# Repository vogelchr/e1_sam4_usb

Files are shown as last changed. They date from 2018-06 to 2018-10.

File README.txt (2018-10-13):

** Review comments for version

commit af33165416c78bff5535539db3183336a3adedb6
    Changed LIU to IDT82V2081.

OPEN:

* Board Bringup
	- due to PLL restrictions we cannot generate PCK 2.048 MHz, have
	  to live with SSC clk output (-> remove sam4s Pin 6,
	     PB3 to TX_CLK, PA21 to CLK2048)
	  
	- LIU spi interface configuration, pull SCLKE up (now: gnd)
	    SCLKE=low: shift SDO on rising edge of SCLK  (datasheet page 13)
	    SCLKE=high: shift SDO on falling edge of SCLK
	  SDI is *always* sampled on the rising edge, so to be consistent
	  SDI will be shifted on the falling edge, so should SDO and SCLKE
	  should be HIGH

	- rename LEDs to match net numbers (LED1..LED3)

* New Features

	For generating the E1 frame sync signal to the SSC peripheral:
	- bridge PA20/Pin16/RF (Receive Frame) to
	         PA27/Pin37/TIOB2 (Timer 2, IO B)
	         
	- bridge PA29/Pin41/TCLK2 (ext. clock input 2 to timer) to
	         PA19/Pin13/RK (Receive Clock)

* Repository / File Formats
	- rename .brd/.sch to sensible name, integrate in old
	   http://cgit.osmocom.org/osmo-e1-xcvr/ repository.

DONE after 20180624:
	- EAGLE 7 compatibility
		(exported _v7 files)
	- make JTAGSEL pullup DNP (JTAGSEL, TEST, ERASE should float)
	- ERASE jumper
	- pullups on i2c
	- pullups on SPI \CSn

	- possibly switch to 82V2081 LUI, as a few people have successfully
	  experimented with it, has access to nice stats over SPI
	  https://www.idt.com/products/interface-connectivity/telecom-interface-products/t1j1e1-interface-products/82v2081-1-channel-t1-j1-e1-short-haullong-haul-liu

DONE after 20180625:
	 - USB has no transient voltage suppressor, possible ESD damage
	 (recommended: IP4234CZ6)
	- R1 120 Ohms (LIU Rx term)
	- R2, R8 9 Ohms (LIU Tx in series)
	- LIU move signal from LOS to #INT 
	  -> Interrupt can be generated on LOS anyway.
	 - diescrete resistors instead of U$2 resistor array is probably lower
	cost in SMT, as it's a standard 10k resistor reel and not one more
	"cut-tape" reel only for that part
		-> introduced quad resistor packs 10k for various pullups
	 - for the DAC, it might make sense to align with what sylvain is using
	in his FPGA based design (and what sysmocom has used in other designs):
	MAX5215 (14bit). Could be upgraded to 16bit MAX5217 if ever needed.
	 - UART has not transient voltage suppressor, possible ESD damage
	(recommended: IP4234CZ6)
	 - JTAG connector doesn't appear to have standard 2x10 ARM-JTAG pin-out.
	If there's space I'd prefer a 20pin ARM-JTAG.
	 - SV3 serial pin-out could be aligned with FTDI 1x5 (or 1x6?) usb
	serial cables. I think it makes sense to align with pin-out of industry
	standard cables that people might already have
	- LEDs near frontpanel
	 - does SPI+I2C header (SV6) have UEXT compatible pin-out? If we use a
	 2x5 header, it might make senese to use the olimex-standard UEXT format
	 as there are plenty of other boards/devices with that pin-out
	 - !RESET has no pull-up, design is possibly susceptible to picking up
	RF/noise as reset trigger
	 - UART has no pull-up resistor on RxD input, i.e. floating input unless
	UART is connected
	- add pullup on LIU #RST
	 - GPS antenna input has no transient voltage suppressor, possible ESD
	damage (unless the
	GNS module has one inside? Did you find any documentation on that in
	the module data sheet? Recommended: 0603ESDA-TR

	 - GPS receiver rx/tx/pps doen't have series termination (27R or
	the like), possibly resulting in switching tranients degrading GPS
	performance

	(this was refused earlier, but later on implemented:)
	 - might make sense to add a precision voltage reference for the DAC,
	e.g. MAX6163ESA?

	- 33R series resistance in oscillator outputs

	- edge type SMA replaced by through hole (edge type incompatible
	  with frontpanel directly on board edge, would have meant to do
	  milling)

REFUSED:
	- interface to old LIU only board (SPI + DATA on pinheader)

	 - 1k series resistors for LEDs seems quite high resistance for 3.3V. I
	would usually expect 330..680 Ohms there?
	  => with modern LEDs it's really bright enough, even with 1k (or even 5k)

	 - If inverted-logic signals would use !SIGNAL instead of #SIGNAL, EAGLE
	would over-stroke their names
	  => (vogelchr) Nice, didn't know this, but will probably not change.

	- USB_VBUS_SENS not routed to microcontroller!
	  device is bus powered, hence monitoring not needed!

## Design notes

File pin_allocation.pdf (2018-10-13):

Po rtA

## Port A Functions

Port# | Pin | A | B | C | D | Extra | SystemNet
0 | 48 | PWMH0 | TIOA0 | A17 | WKUP0 | GPS_PPS
1 | 47 | PWMH1 | TIOB0 | A18 | WKUP1 | TP8
2 | 44 | PWMH2 | SCK0 | DATRG | WKUP2 | TP9
3 | 43 | TWD0 | NPCS3 | I2C
4 | 36 | TWCK0 | TCLK0 | WKUP3 | I2C
5 | 35 | RXD0 | NPCS3 | WKUP4 | GPS_RX
6 | 34 | TXD0 | PCK0 | GPS_TX
7 | 32 | RTS0 | PWMH3 | XIN32 LOS_LIU
8 | 31 | CTS0 | ADTRG | WKUP5 | XOUT32#RST_LIU
9 | 30 | URXD0 | NPCS1 | PWMFI0 | WKUP6 | URXD0_SAMBA_RX
10 | 29 | UTXD0 | NPCS2 | PWMFI1 | UTXD0_SAMBA_TX
11 | 28 | NPCS0 | PWMH0 | WKUP7 | #SPI_CS0
12 | 27 | MISO | PWMH1 | SPI_MISO
13 | 22 | MOSI | PWMH2 | SPI_MOSO
14 | 21 | SPCK | PWMH3 | WKUP8 | SPI_SCK
15 | 20 | TF | TIOA1 | PWML3 | WKUP14 /PIODCEN1 | TP13
16 | 19 | TK | TIOB1 | PWML2 | WKUP15/PIODCEN2 TX_CLK | input!
17 | 9 | TD | PCK1 | PWMH3 | AD0 | TX_DATA | output
18 | 10 | RD | PCK2 | A14 | PWMFI2AD1 | RX_DATA | inout
19 | 13 | RK | PWML0 | A15 | AD2 | RX_CLK | input
20 | 16 | RF | PWML1 | A16 | AD3 | (rx_frame) | TP10
21 | 11 | RXD1 | PCK1 | AD8 | CLK2048 (to LIU)
22 | 14 | TXD1 | NPCS3 | NCS2 | AD9 | TP11
23 | 15 | SCK1 | PWMH0 | A19 | PIODCCLK | TP12
24 | 23 | RTS1 | PWMH1 | A20 | PIODC0 | LED1
25 | 25 | CTS1 | PWMH2 | A23 | PIODC1 | LED2
26 | 26 | DCD1 | TIOA2 | MCDA2 | PIODC2 | LED3
27 | 37 | DTR1 | TIOB2 | MCDA3 | PIODC3 | (rx_frame) | TP14
28 | 38 | DSR1 | TCLK1 | MCCDA | PIODC4 | TP15
29 | 41 | RI1 | TCLK2 | MCCK | PIODC5 | TP16
30 | 42 | PWML2 | NPCS2 | MCDA0 | WKUP11/PIODC6 | SPI_CS2
31 | 52 | NPCS1 | PCK2 | MCDA1 | PIODC7 | SPI_CS1
Inst | TC0 PWM TWI0 UART0 USART0 USART1 SSC SPI

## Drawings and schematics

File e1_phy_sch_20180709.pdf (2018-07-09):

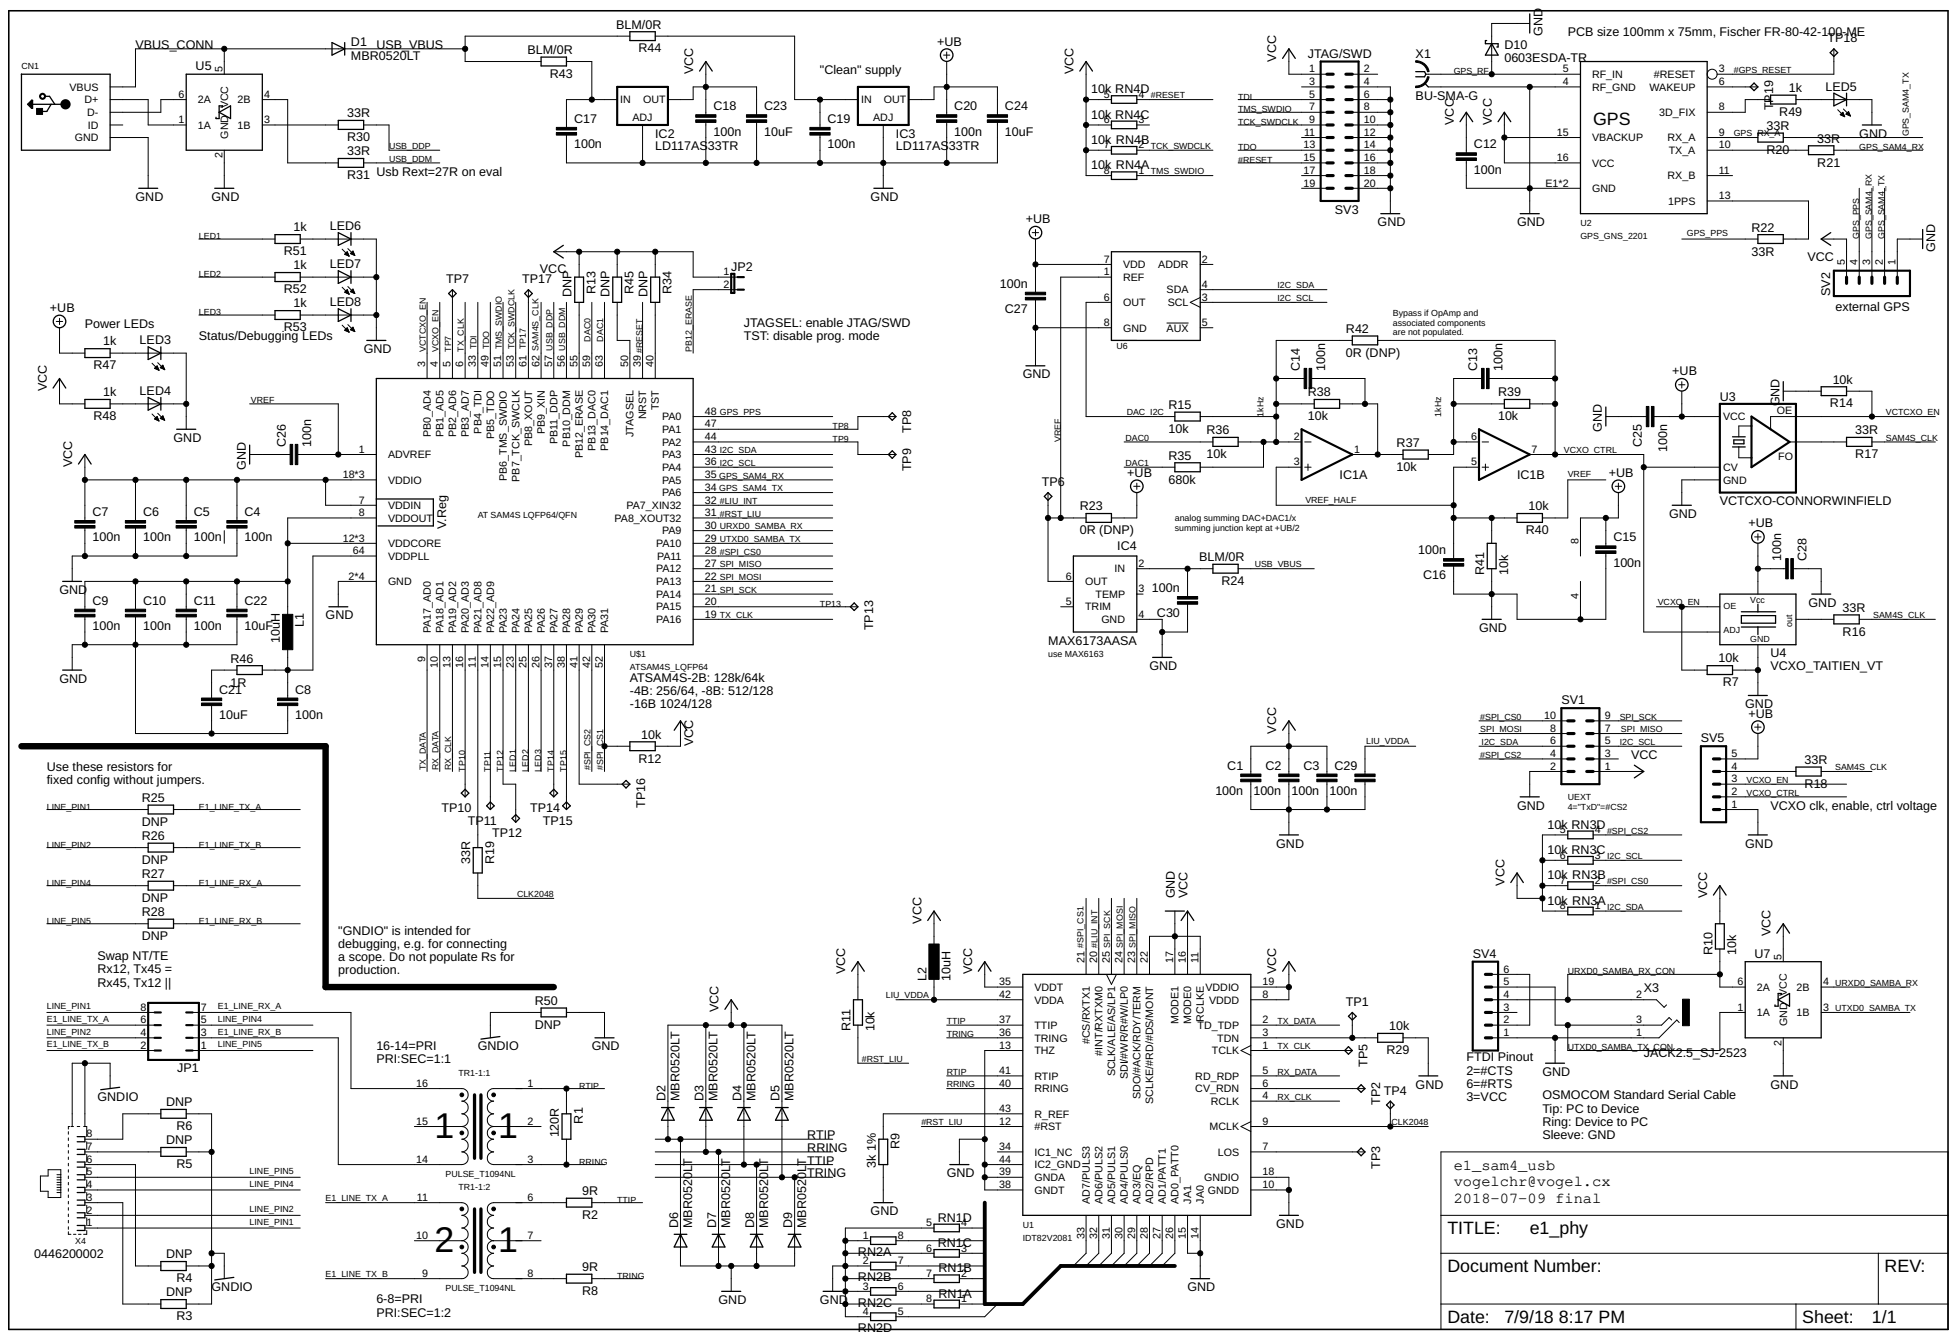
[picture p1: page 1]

PCB size 100mm x 75mm, Fischer FR-80-42-100-ME

Bypass if OpAmp and
associated components are not populated.

JTAGSEL: enable JTAG/SWD
TST: disable prog. mode

analog summing DAC+DAC1/x
summing junction kept at +UB/2

Use these resistors for
fixed config without jumpers.

DNP DNP

"GNDIO" is intended for debugging, e.g. for connecting
a scope. Do not populate Rs for production.

24 SDO/#ACK/RDY/TERM

23 SCLKE/#RD/#DS/MONT

OSMOCOM Standard Serial Cable Tip: PC to Device Ring: Device to PC

e1_sam4_usb
vogelchr@vogel.cx
2018-07-09 final
REV: TITLE: Document Number: e1_phy

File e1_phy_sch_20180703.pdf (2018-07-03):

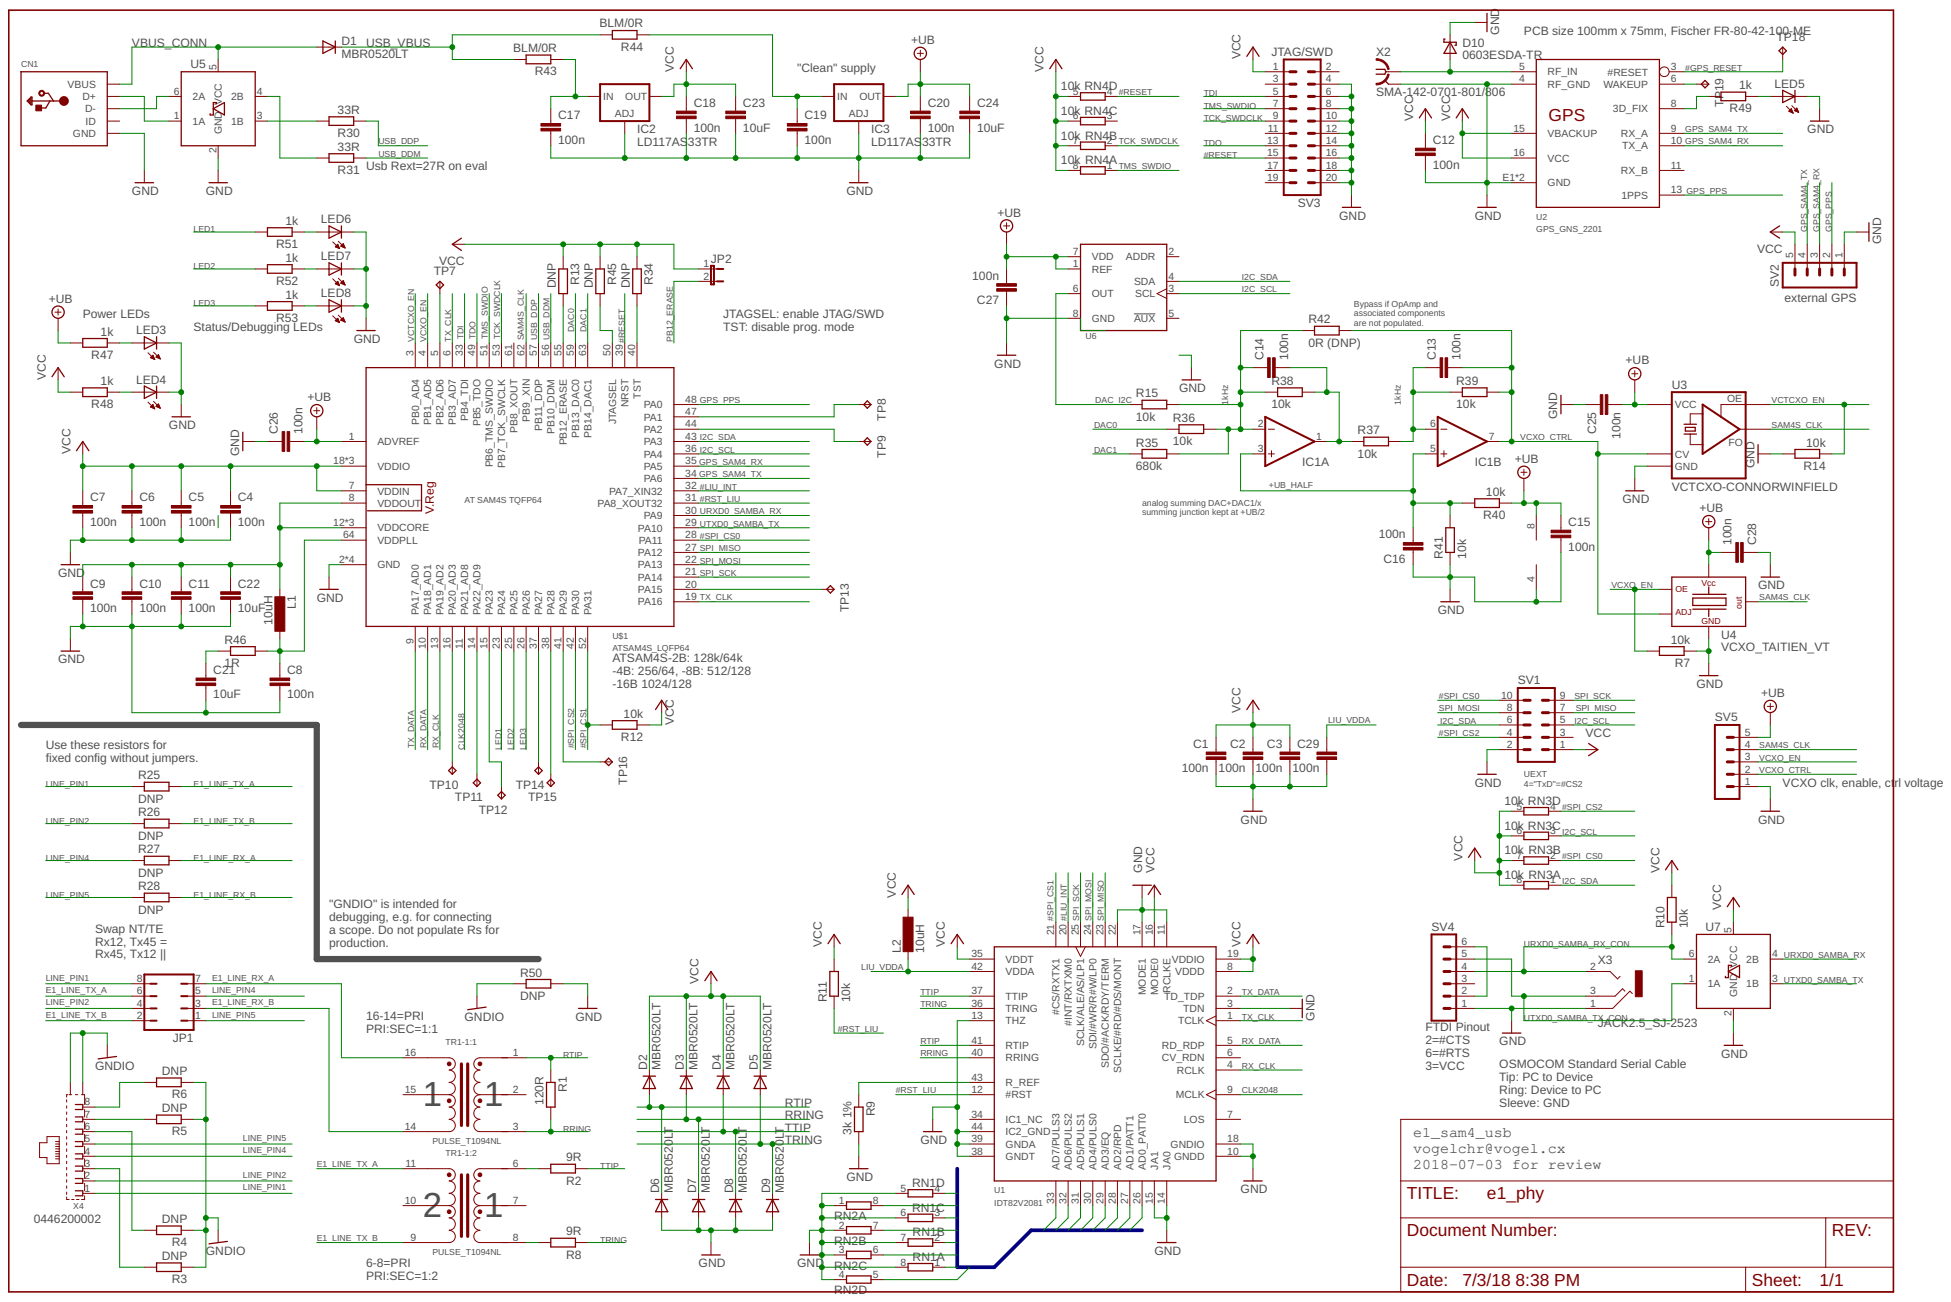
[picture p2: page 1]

PCB size 100mm x 75mm, Fischer FR-80-42-100-ME

JTAGSEL: enable JTAG/SWD
TST: disable prog. mode

Bypass if OpAmp and
associated components are not populated.

analog summing DAC+DAC1/x
summing junction kept at +UB/2

64 | #SPI_CS0
2*4 | 27 PA11 SPI_MISO

Use these resistors for
fixed config without jumpers.

DNP DNP

"GNDIO" is intended for debugging, e.g. for connecting

a scope. Do not populate Rs for production.

24 SDO/#ACK/RDY/TERM

23 SCLKE/#RD/#DS/MONT

OSMOCOM Standard Serial Cable Tip: PC to Device Ring: Device to PC

e1_sam4_usb
vogelchr@vogel.cx
2018-07-03 for review
REV: TITLE: Document Number: e1_phy

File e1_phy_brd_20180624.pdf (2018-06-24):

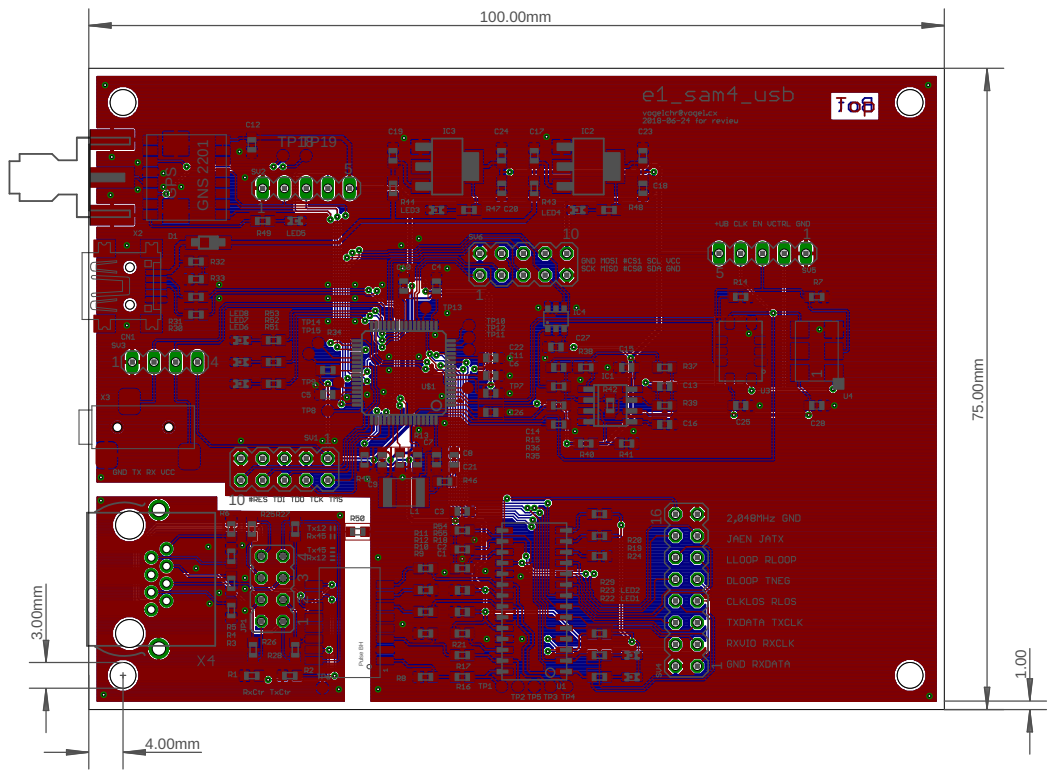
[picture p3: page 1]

61PT 71PT 1 2 3 4 Pulse BH GNS 2201 GPS 1 10 1 5 1 4 1 16 1 10 1 5 1 TP1T8P19 100.00mm 75.00mm 4.00mm 3.00mm 1.00

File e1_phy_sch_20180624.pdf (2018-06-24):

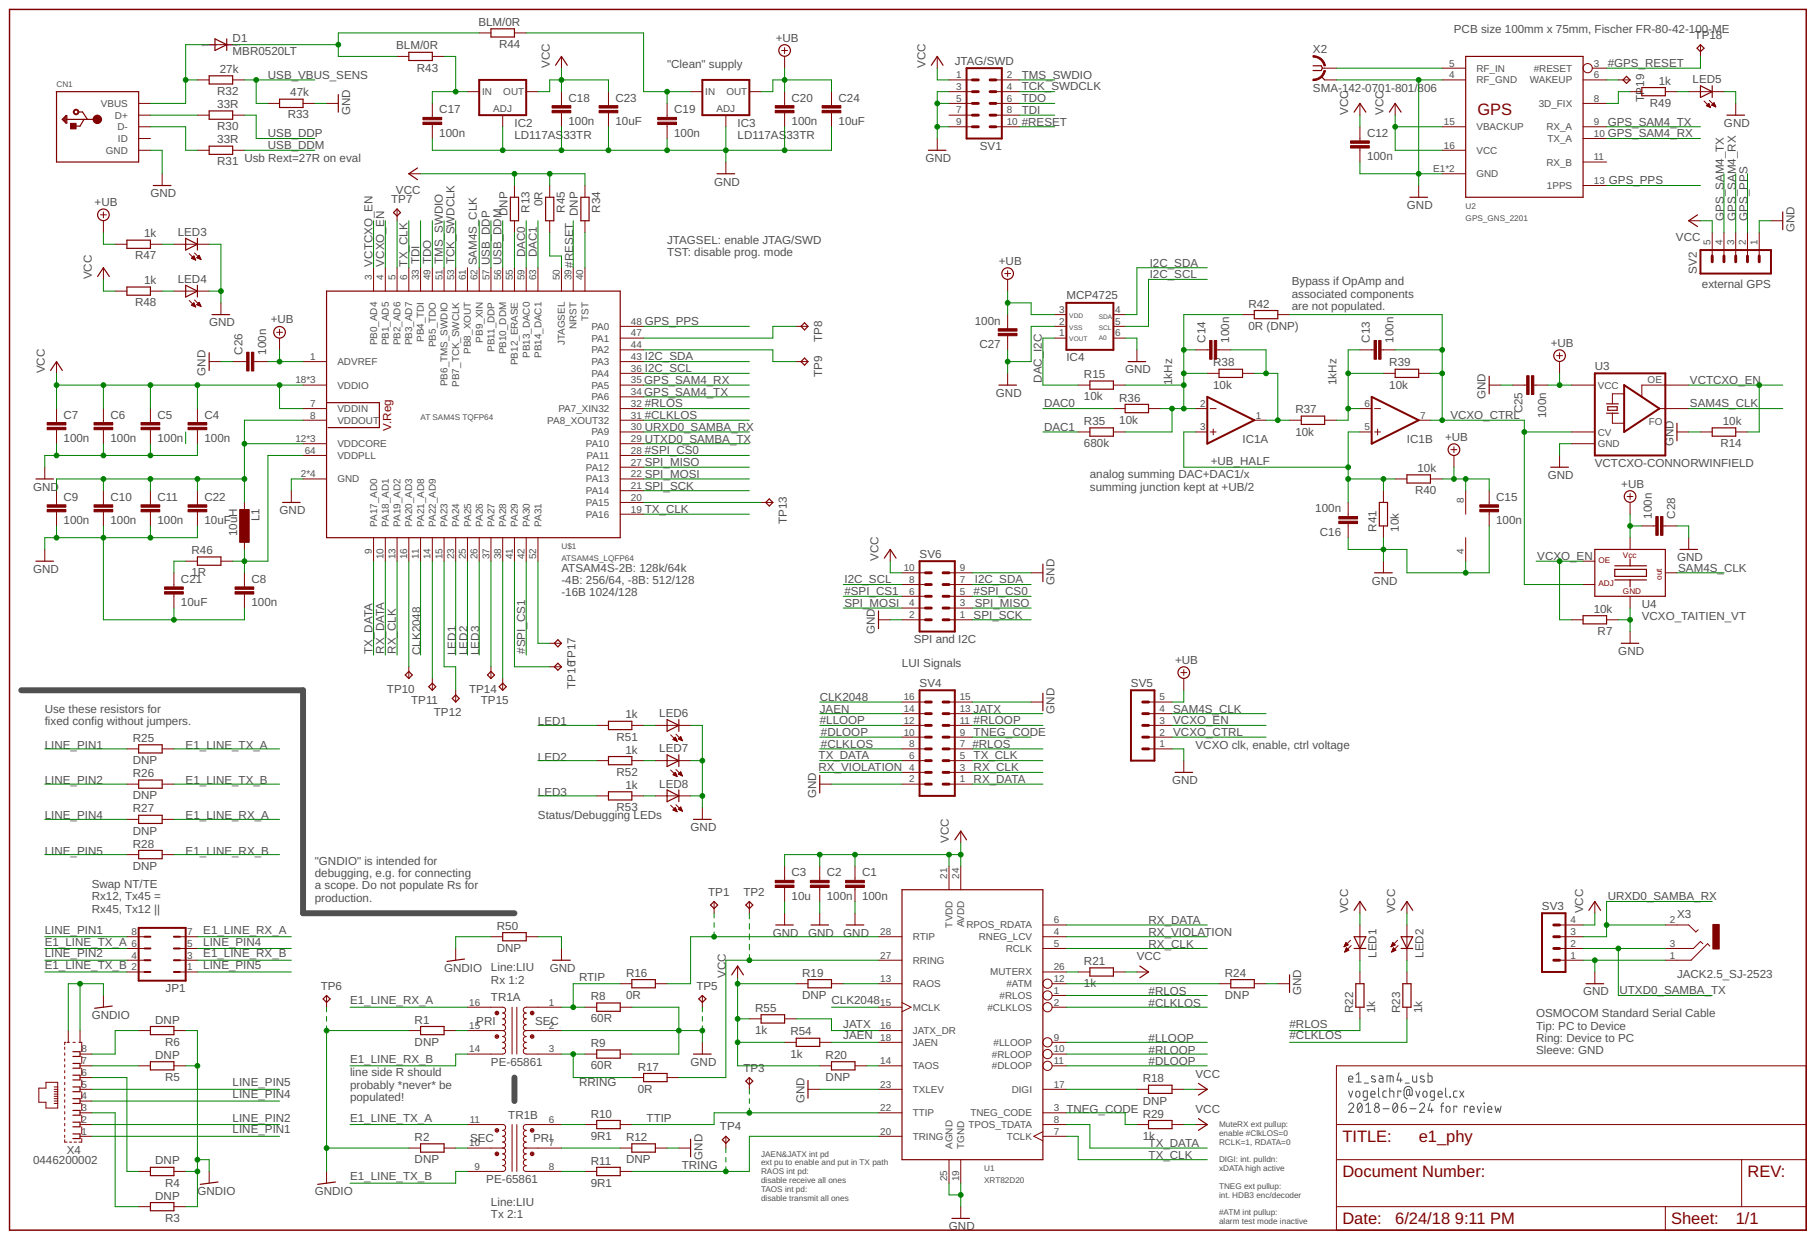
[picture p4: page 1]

PCB size 100mm x 75mm, Fischer FR-80-42-100-ME

Usb Rext=27R on eval

JTAGSEL: enable JTAG/SWD
TST: disable prog. mode

Bypass if OpAmp and

analog summing DAC+DAC1/x
summing junction kept at +UB/2

Use these resistors for
fixed config without jumpers.
LINE_PIN1

DNP DNP

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

OSMOCOM Standard Serial Cable Tip: PC to Device Ring: Device to PC

MuteRX ext pullup: enable #ClkLOS=0 RCLK=1, RDATA=0 DIGI: int. pulldn: xDATA high active TNEG ext pullup:

REV: TITLE: Document Number: e1_phy

JAEN&JATX int pd
ext pu to enable and put in TX path RAOS int pd: disable receive all ones TAOS int pd: disable transmit all ones

int. HDB3 enc/decoder #ATM int pullup: alarm test mode inactive

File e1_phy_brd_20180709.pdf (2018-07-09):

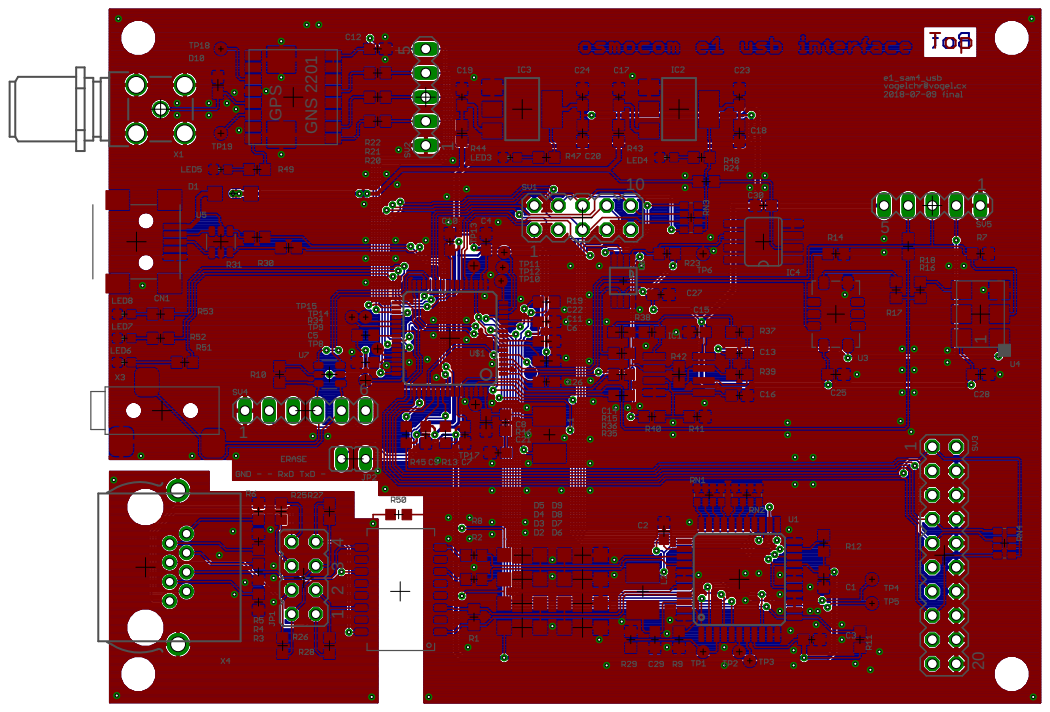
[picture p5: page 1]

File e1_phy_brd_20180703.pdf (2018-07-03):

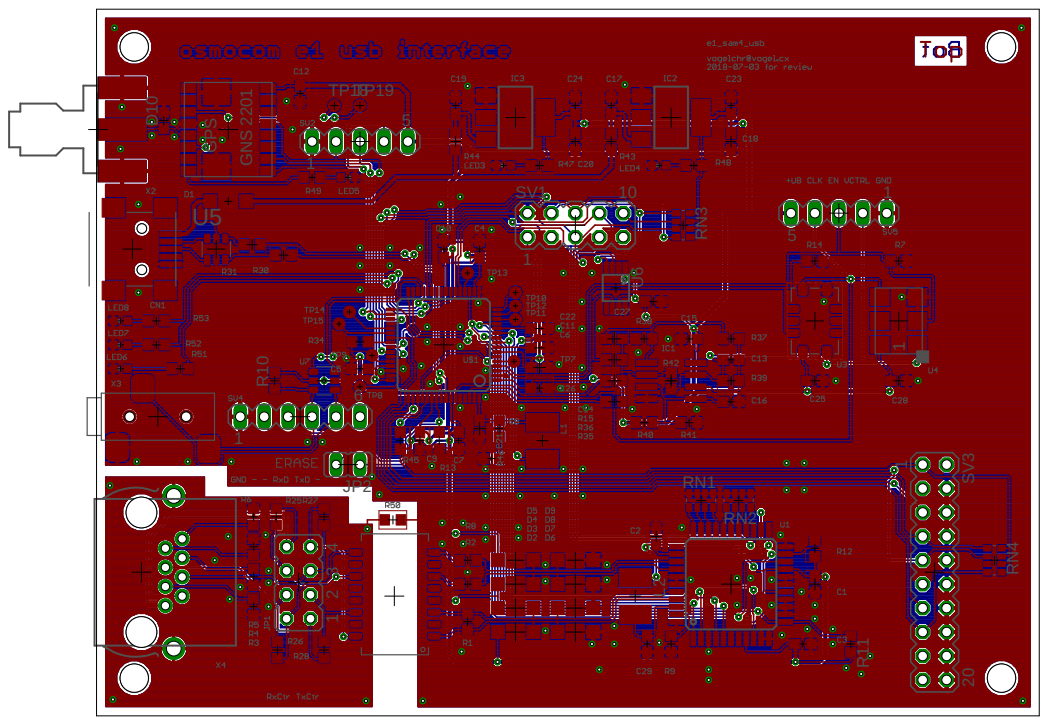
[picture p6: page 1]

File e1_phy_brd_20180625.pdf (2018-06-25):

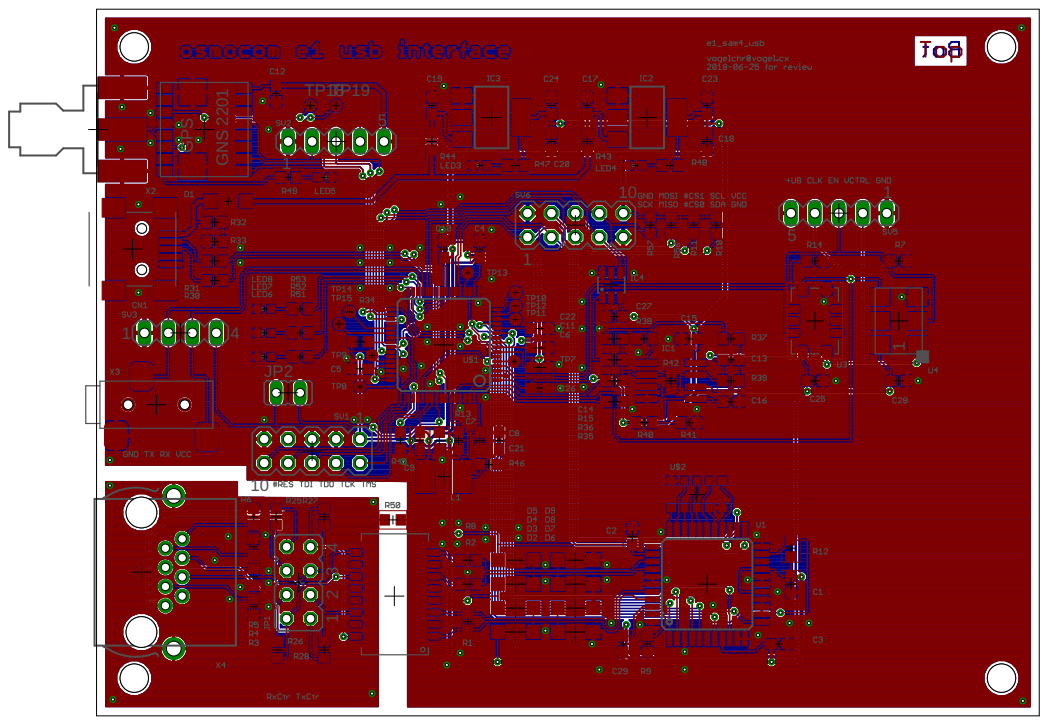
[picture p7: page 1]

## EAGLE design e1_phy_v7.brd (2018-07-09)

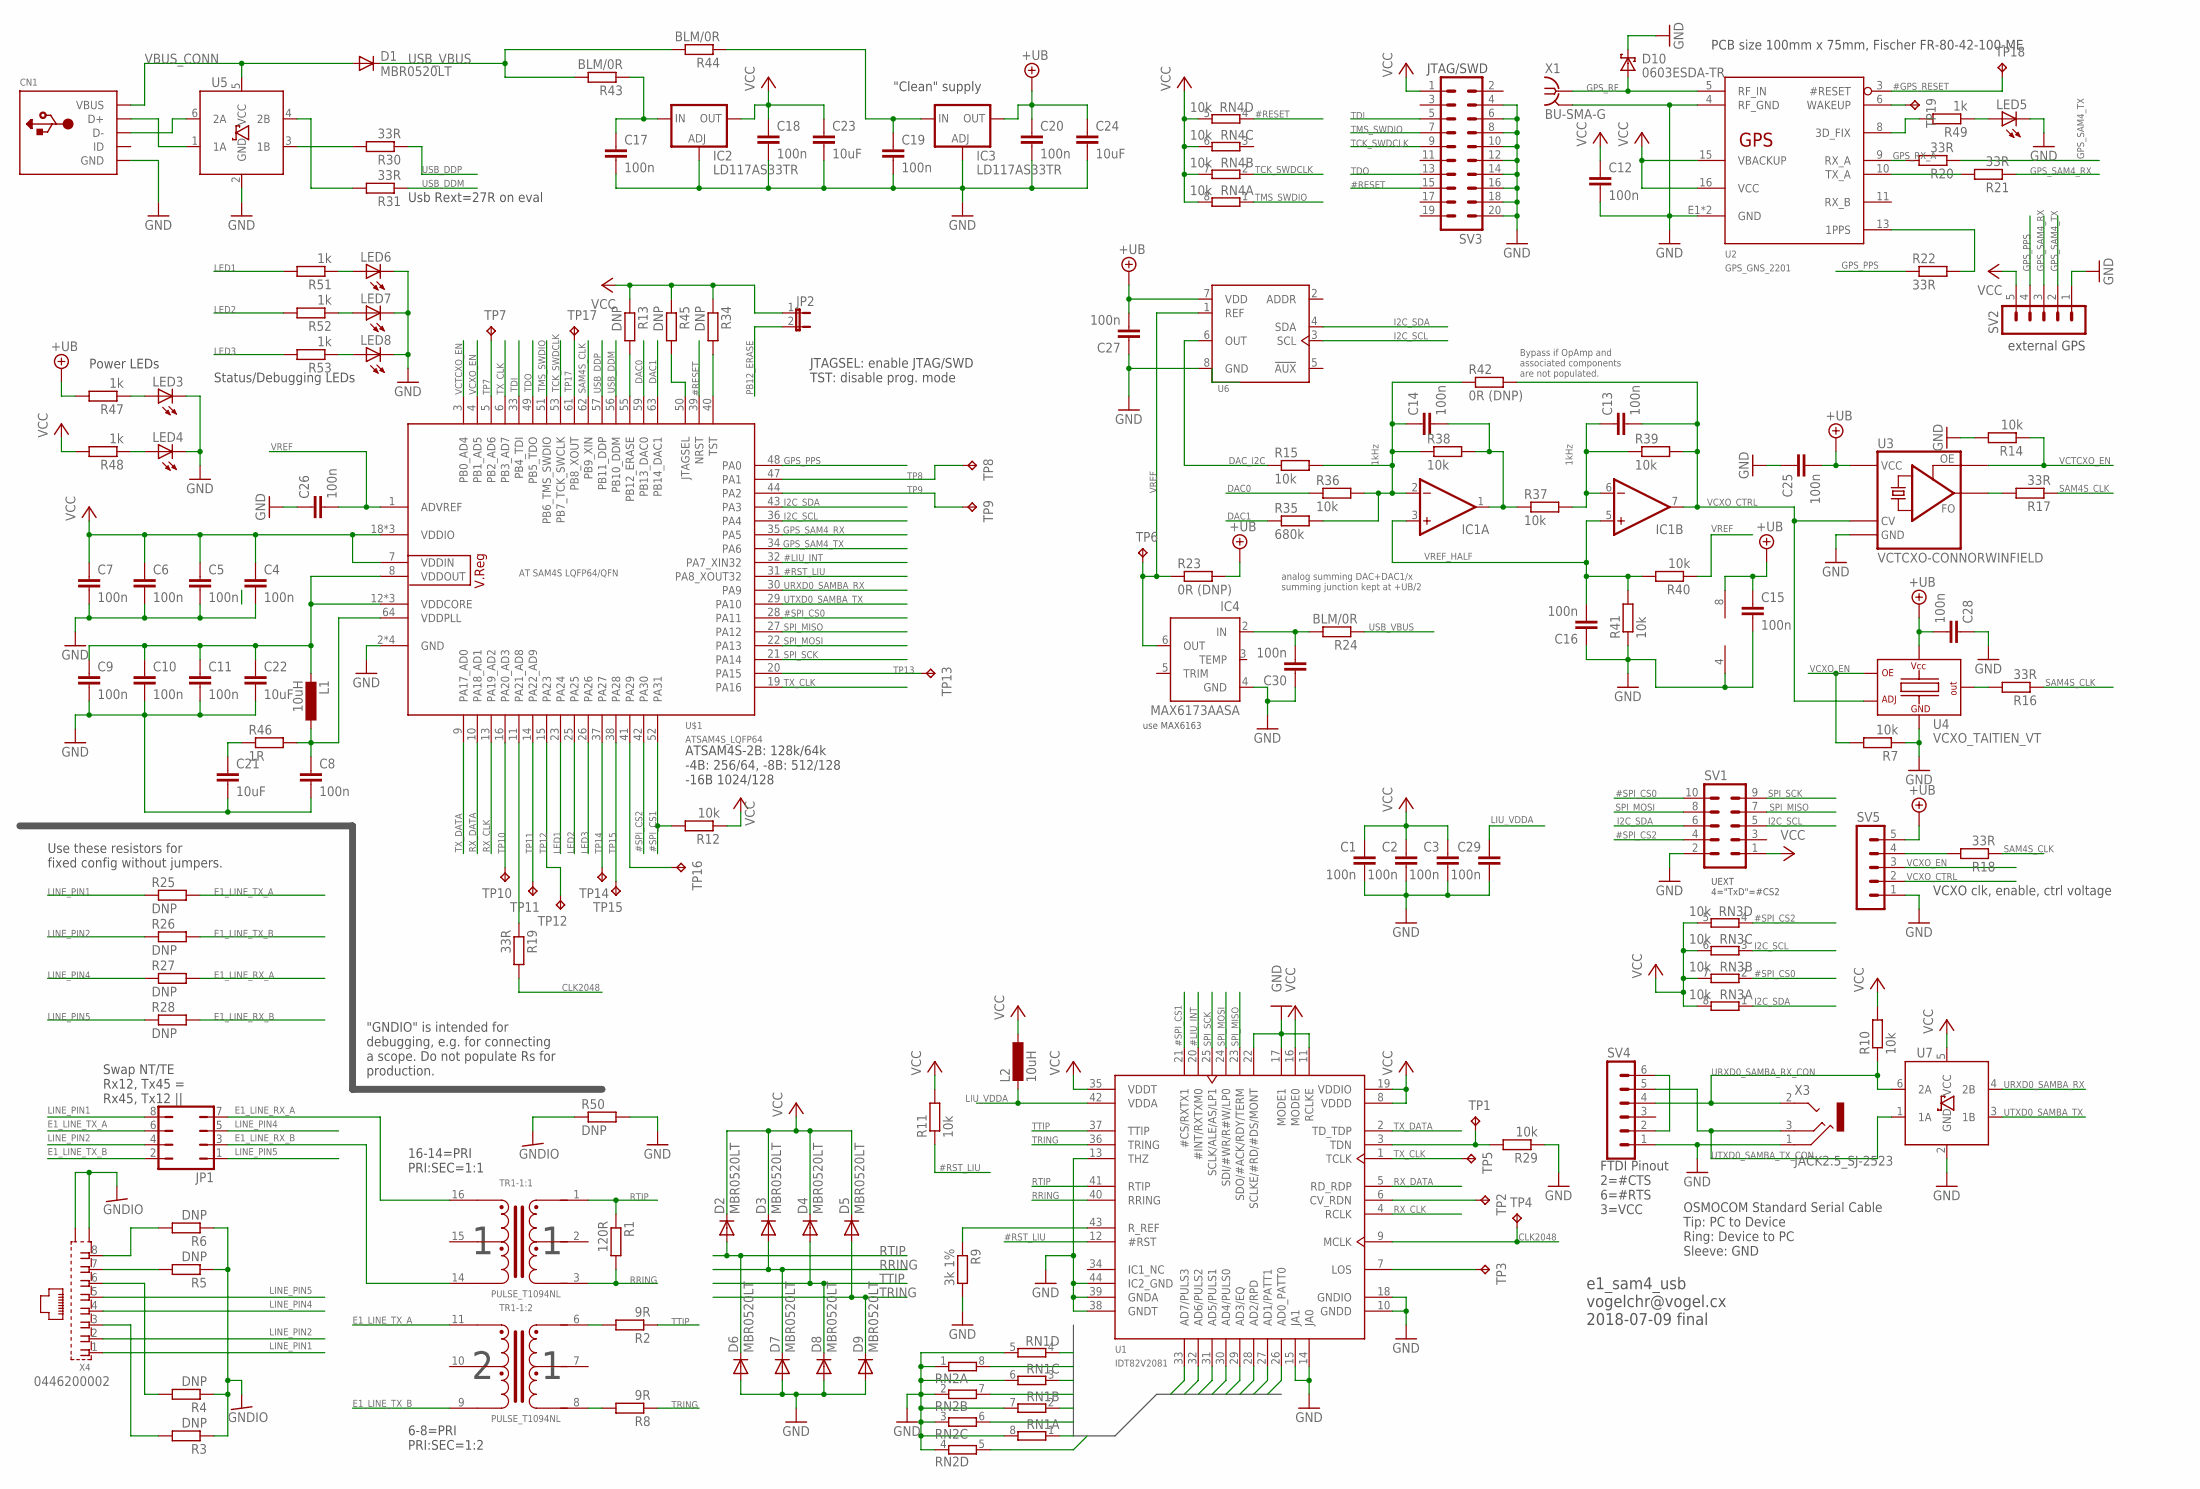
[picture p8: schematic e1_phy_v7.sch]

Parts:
C1, C2, C3, C4, C5, C6, C7, C8, C9, C10, C11, C12, C13, C14, C15, C16, C17, C18, C19, C20, C25, C26, C27, C28, C29, C30: 100n; C0603
C21, C22, C23, C24: 10uF; C0603
CN1: USBMINIB; USB-MINIB
D1, D2, D3, D4, D5, D6, D7, D8, D9: MBR0520LT; SOD123
D10: 0603ESDA-TR; 0603
IC1: 2AMP_P8+4D; SO08
IC2, IC3: LD117AS33TR; SOT223
IC4: MAX6173AASA; SO08
JP1: JP4Q
JP2: JP1E; JP1
L1, L2: 10uH; L1812
LED3, LED4, LED5, LED6, LED7, LED8: LEDCHIPLED_0603; CHIPLED_0603
R1: 120R; R0603
R2, R8: 9R; R0603
R3, R4, R5, R6, R13, R25, R26, R27, R28, R34, R45, R50: DNP; R0603
R7, R10, R11, R12, R14, R15, R29, R36, R37, R38, R39, R40, R41: 10k; R0603
R9: 3k 1%; R0603
R16, R17, R18, R19, R20, R21, R22, R30, R31: 33R; R0603
R23, R42: 0R (DNP); R0603
R24, R43, R44: BLM/0R; R0603
R35: 680k; R0603
R46: 1R; R0603
R47, R48, R49, R51, R52, R53: 1k; R0603
RN1, RN2: 4R-NEXB38V; EXB38V
RN3, RN4: 10k; EXB38V
SV1: MA05-2
SV2, SV5: MA05-1
SV3: MA10-2
SV4: MA06-1
TP1, TP2, TP3, TP4, TP5, TP6, TP7, TP8, TP9, TP10, TP11, TP12, TP13, TP14, TP15, TP16, TP17, TP18, TP19: TPB1,27; B1,27
TR1: PULSE_T1094NL; PULSE_BH
U1: IDT82V2081; TQFP44
U2: GPS_GNS_2201
U3: VCTCXO-CONNORWINFIELD
U4: VCXO_TAITIEN_VT; VCXO_TAITIEN_VT_7MM_5MM
U5, U7: IP4234CZ6; TSOP-6
U6: MAX521X; UMAX8
U$1: ATSAM4S_LQFP64; LQFP-ST-64-2
X1: BU-SMA-G
X3: JACK2.5_SJ-2523
X4: 0446200002

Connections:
#GPS_RESET: TP18.TP, U2.3 (#RESET)
#LIU_INT: U1.20 (#INT/RXTXM0), U$1.32 (PA7_XIN32)
#RESET: RN4.4 (1), SV3.15, U$1.39 (NRST)
#RST_LIU: R11.1, U1.12 (#RST), U$1.31 (PA8_XOUT32)
#SPI_CS0: RN3.2 (1), SV1.10, U$1.28 (PA11)
#SPI_CS1: R12.2, U1.21 (#CS/RXTX1), U$1.52 (PA31)
#SPI_CS2: RN3.4 (1), SV1.4, U$1.42 (PA30)
+UB: C15.1, C20.1, C24.1, C25.2, C27.2, C28.2, IC1.8 (V+), IC3.4 (OUT), R23.2, R47.2, SV5.5, U3.9 (VCC), U4.6 (VCC), U6.7 (VDD)
AD0: RN2.8 (2), U1.26 (AD0_PATT0)
AD1: RN2.7 (2), U1.27 (AD1/PATT1)
AD2: RN2.6 (2), U1.28 (AD2/RPD)
AD3: RN2.5 (2), U1.29 (AD3/EQ)
AD4: RN1.4 (1), U1.30 (AD4/PULS0)
AD5: RN1.3 (1), U1.31 (AD5/PULS1)
AD6: RN1.2 (1), U1.32 (AD6/PULS2)
AD7: RN1.1, U1.33 (AD7/PULS3)
CLK2048: R19.2, TP4.TP, U1.9 (MCLK)
CLK2048_SAM4S: R19.1, U$1.11 (PA21_AD8)
DAC0: R36.1, U$1.59 (PB13_DAC0)
DAC1: R35.1, U$1.63 (PB14_DAC1)
DAC_I2C: R15.1, U6.6 (OUT)
E1_LINE_RX_A: JP1.7, R27.2, TR1.16
E1_LINE_RX_B: JP1.3, R28.2, TR1.14
E1_LINE_TX_A: JP1.6, R25.2, TR1.11
E1_LINE_TX_B: JP1.2, R26.2, TR1.9
GND: C1.2, C2.2, C3.2, C4.2, C5.2, C6.2, C7.2, C8.2, C9.2, C10.2, C11.2, C12.2, C15.2, C16.1, C17.2, C18.2, C19.2, C20.2, C21.2, C22.2, C23.2, C24.2, C25.1, C26.1, C27.1, C28.1, C29.2, C30.1, CN1.GND, D6.A, D7.A, D8.A, D9.A, D10.2 (K), IC1.4 (V-), IC2.1 (ADJ), IC3.1 (ADJ), IC4.4 (GND), LED3.C, LED4.C, LED5.C, LED6.C, LED7.C, LED8.C, R7.1, R9.2, R14.2, R29.1, R41.1, R50.2, RN1.5 (2), RN1.6 (2), RN1.7 (2), RN1.8 (2), RN2.1, RN2.2 (1), RN2.3 (1), RN2.4 (1), SV1.2, SV2.1, SV3.4, SV3.6, SV3.8, SV3.10, SV3.12, SV3.14, SV3.16, SV3.18, SV3.20, SV4.1, SV5.1, U1.10 (GNDD), U1.11 (RCLKE), U1.13 (THZ), U1.14 (JA0), U1.15 (JA1), U1.17 (MODE1), U1.18 (GNDIO), U1.22 (SCLKE/#RD/#DS/MONT), U1.38 (GNDT), U1.39 (GNDA), U1.44 (IC2_GND), U2.4 (RF_GND), U2.E1 (GND), U2.E2 (GND), U3.4 (GND), U4.3 (GND), U5.2 (GND), U6.8 (GND), U7.2 (GND), U$1.2 (GND), U$1.17 (GND), U$1.46 (GND), U$1.60 (GND), X1.2, X1.3 (2), X1.4 (2), X1.5 (2), X3.1 (RING)
GNDIO: R3.1, R4.1, R5.1, R6.1, R50.1, X4.S@1 (S1), X4.S@2 (S2)
GPS_3DFIX: R49.2, U2.8 (3D_FIX)
GPS_PPS: R22.1, SV2.4, U$1.48 (PA0)
GPS_RF: D10.1 (A), U2.5 (RF_IN), X1.1
GPS_RX_A: R20.2, U2.9 (RX_A)
GPS_SAM4_RX: R21.1, SV2.3, U$1.35 (PA5)
GPS_SAM4_TX: R20.1, SV2.2, U$1.34 (PA6)
GPS_WAKEUP: TP19.TP, U2.6 (WAKEUP)
I2C_SCL: RN3.3 (1), SV1.5, U6.3 (SCL), U$1.36 (PA4)
I2C_SDA: RN3.1, SV1.6, U6.4 (SDA), U$1.43 (PA3)
JTAGSEL: R45.2, U$1.50 (JTAGSEL)
LED1: R51.2, U$1.23 (PA24)
LED2: R52.2, U$1.25 (PA25)
LED3: R53.2, U$1.26 (PA26)
LINE_PIN1: JP1.8, R25.1, X4.1
LINE_PIN2: JP1.4, R26.1, X4.2
LINE_PIN3: R3.2, X4.3
LINE_PIN4: JP1.5, R27.1, X4.4
LINE_PIN5: JP1.1, R28.1, X4.5
LINE_PIN6: R4.2, X4.6
LINE_PIN7: R5.2, X4.7
LINE_PIN8: R6.2, X4.8
LIU_VDDA: C29.1, L2.2, U1.42 (VDDA)
unnamed: CN1.D+, U5.1 (1A)
unnamed: CN1.D-, U5.6 (2A)
unnamed: TP2.TP, U1.6 (CV_RDN)
unnamed: R2.2, TR1.6
unnamed: R29.2, TP1.TP, U1.3 (TDN)
unnamed: TP3.TP, U1.7 (LOS)
unnamed: C30.2, IC4.2 (IN), R24.2
unnamed: LED5.A, R49.1
unnamed: C19.1, IC3.3 (IN), R44.1
unnamed: C17.1, IC2.3 (IN), R43.1
unnamed: C21.1, R46.1
unnamed: LED3.A, R47.1
unnamed: TP16.TP, U$1.41 (PA29)
unnamed: LED4.A, R48.1
unnamed: R8.2, TR1.8
unnamed: LED6.A, R51.1
unnamed: LED7.A, R52.1
unnamed: LED8.A, R53.1
unnamed: R22.2, U2.13 (1PPS)
unnamed: R9.1, U1.43 (R_REF)
unnamed: SV4.2, SV4.6
OPAMP1_IN_NEG: C14.1, IC1.2 (-IN), R15.2, R35.2, R36.2, R38.1, R42.1
OPAMP1_OUT: C14.2, IC1.1 (OUT), R37.1, R38.2
OPAMP2_IN_NEG: C13.1, IC1.6 (-IN), R37.2, R39.1
PB12_ERASE: JP2.2, R13.2, U$1.55 (PB12_ERASE)
RRING: D3.A, D7.C, R1.2, TR1.3, U1.40 (RRING)
RTIP: D2.A, D6.C, R1.1, TR1.1, U1.41 (RTIP)
RX_CLK: U1.4 (RCLK), U$1.13 (PA19_AD2)
RX_DATA: U1.5 (RD_RDP), U$1.10 (PA18_AD1)
SAM4S_CLK: R16.1, R17.1, R18.1, U$1.62 (PB9_XIN)
SAM4S_CLK_EXT: R18.2, SV5.4
SAM4S_CLK_VCTXO: R17.2, U3.5 (FO)
SAM4S_CLK_VCXO: R16.2, U4.4 (Q)
SPI_MISO: SV1.7, U1.23 (SDO/#ACK/RDY/TERM), U$1.27 (PA12)
SPI_MOSI: SV1.8, U1.24 (SDI/#WR/R#W/LP0), U$1.22 (PA13)
SPI_SCK: SV1.9, U1.25 (SCLK/ALE/AS/LP1), U$1.21 (PA14)
TCK_SWDCLK: RN4.2 (1), SV3.9, U$1.53 (PB7_TCK_SWCLK)
TDI: SV3.5, U$1.33 (PB4_TDI)
TDO: SV3.13, U$1.49 (PB5_TDO)
TMS_SWDIO: RN4.1, SV3.7, U$1.51 (PB6_TMS_SWDIO)
TP7: TP7.TP, U$1.5 (PB2_AD6)
TP8: TP8.TP, U$1.47 (PA1)
TP9: TP9.TP, U$1.44 (PA2)
TP10: TP10.TP, U$1.16 (PA20_AD3)
TP11: TP11.TP, U$1.14 (PA22_AD9)
TP12: TP12.TP, U$1.15 (PA23)
TP13: TP13.TP, U$1.20 (PA15)
TP14: TP14.TP, U$1.37 (PA27)
TP15: TP15.TP, U$1.38 (PA28)
TP17: TP17.TP, U$1.61 (PB8_XOUT)
TPS_TX_A: R21.2, U2.10 (TX_A)
TRING: D5.A, D9.C, R8.1, U1.36 (TRING)
TST: R34.2, U$1.40 (TST)
TTIP: D4.A, D8.C, R2.1, U1.37 (TTIP)
TX_CLK: TP5.TP, U1.1 (TCLK), U$1.6 (PB3_AD7), U$1.19 (PA16)
TX_DATA: U1.2 (TD_TDP), U$1.9 (PA17_AD0)
URXD0_SAMBA_RX: U7.4 (2B), U$1.30 (PA9)
URXD0_SAMBA_RX_CON: R10.1, SV4.4, U7.6 (2A), X3.2 (TIP)
USB_DDM: R31.1, U$1.56 (PB10_DDM)
USB_DDM_CON: R31.2, U5.4 (2B)
USB_DDP: R30.1, U$1.57 (PB11_DDP)
USB_DDP_CON: R30.2, U5.3 (1B)
USB_VBUS: D1.C, R24.1, R43.2, R44.2
UTXD0_SAMBA_TX: U7.3 (1B), U$1.29 (PA10)
UTXD0_SAMBA_TX_CON: SV4.5, U7.1 (1A), X3.3 (MIDDLE)
VBUS_CONN: CN1.VBUS, D1.A, U5.5 (VCC)
VCC: C1.1, C2.1, C3.1, C4.1, C5.1, C6.1, C7.1, C12.1, C18.1, C23.1, D2.C, D3.C, D4.C, D5.C, IC2.4 (OUT), JP2.1, L2.1, R10.2, R11.2, R12.1, R13.1, R34.1, R45.1, R48.2, RN3.5 (2), RN3.6 (2), RN3.7 (2), RN3.8 (2), RN4.5 (2), RN4.6 (2), RN4.7 (2), RN4.8 (2), SV1.1, SV2.5, SV3.1, U1.8 (VDDD), U1.16 (MODE0), U1.19 (VDDIO), U1.35 (VDDT), U2.15 (VBACKUP), U2.16 (VCC), U7.5 (VCC), U$1.7 (VDDIN), U$1.18 (VDDIO), U$1.45 (VDDIO), U$1.58 (VDDIO)
VCTCXO_EN: R14.1, U3.8 (OE), U$1.3 (PB0_AD4)
VCXO_CTRL: C13.2, IC1.7 (OUT), R39.2, R42.2, SV5.2, U3.10 (CV), U4.1 (VADJ)
VCXO_EN: R7.2, SV5.3, U4.2 (OE), U$1.4 (PB1_AD5)
VDDCORE: C9.1, C10.1, C11.1, C22.1, L1.2, U$1.8 (VDDOUT), U$1.12 (VDDCORE), U$1.24 (VDDCORE), U$1.54 (VDDCORE)
VDDPLL: C8.1, L1.1, R46.2, U$1.64 (VDDPLL)
VREF: C26.2, IC4.6 (OUT), R23.1, R40.1, TP6.TP, U6.1 (REF), U$1.1 (ADVREF)
VREF_HALF: C16.2, IC1.3 (+IN), IC1.5 (+IN), R40.2, R41.2

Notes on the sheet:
Swap NT/TE Rx12, Tx45 = Rx45, Tx12 ||
Use these resistors for fixed config without jumpers.
"GNDIO" is intended for debugging, e.g. for connecting a scope. Do not populate Rs for production.
Bypass if OpAmp and associated components are not populated.
1kHz
analog summing DAC+DAC1/x summing junction kept at +UB/2
"Clean" supply
JTAGSEL: enable JTAG/SWD TST: disable prog. mode
JTAG/SWD
external GPS
OSMOCOM Standard Serial Cable Tip: PC to Device Ring: Device to PC Sleeve: GND
ATSAM4S-2B: 128k/64k -4B: 256/64, -8B: 512/128 -16B 1024/128
Usb Rext=27R on eval
PCB size 100mm x 75mm, Fischer FR-80-42-100-ME
Status/Debugging LEDs
VCXO clk, enable, ctrl voltage
16-14=PRI PRI:SEC=1:1
6-8=PRI PRI:SEC=1:2
e1_sam4_usb vogelchr@vogel.cx 2018-07-09 final
FTDI Pinout 2=#CTS 6=#RTS 3=VCC
UEXT 4="TxD"=#CS2
Power LEDs
use MAX6163

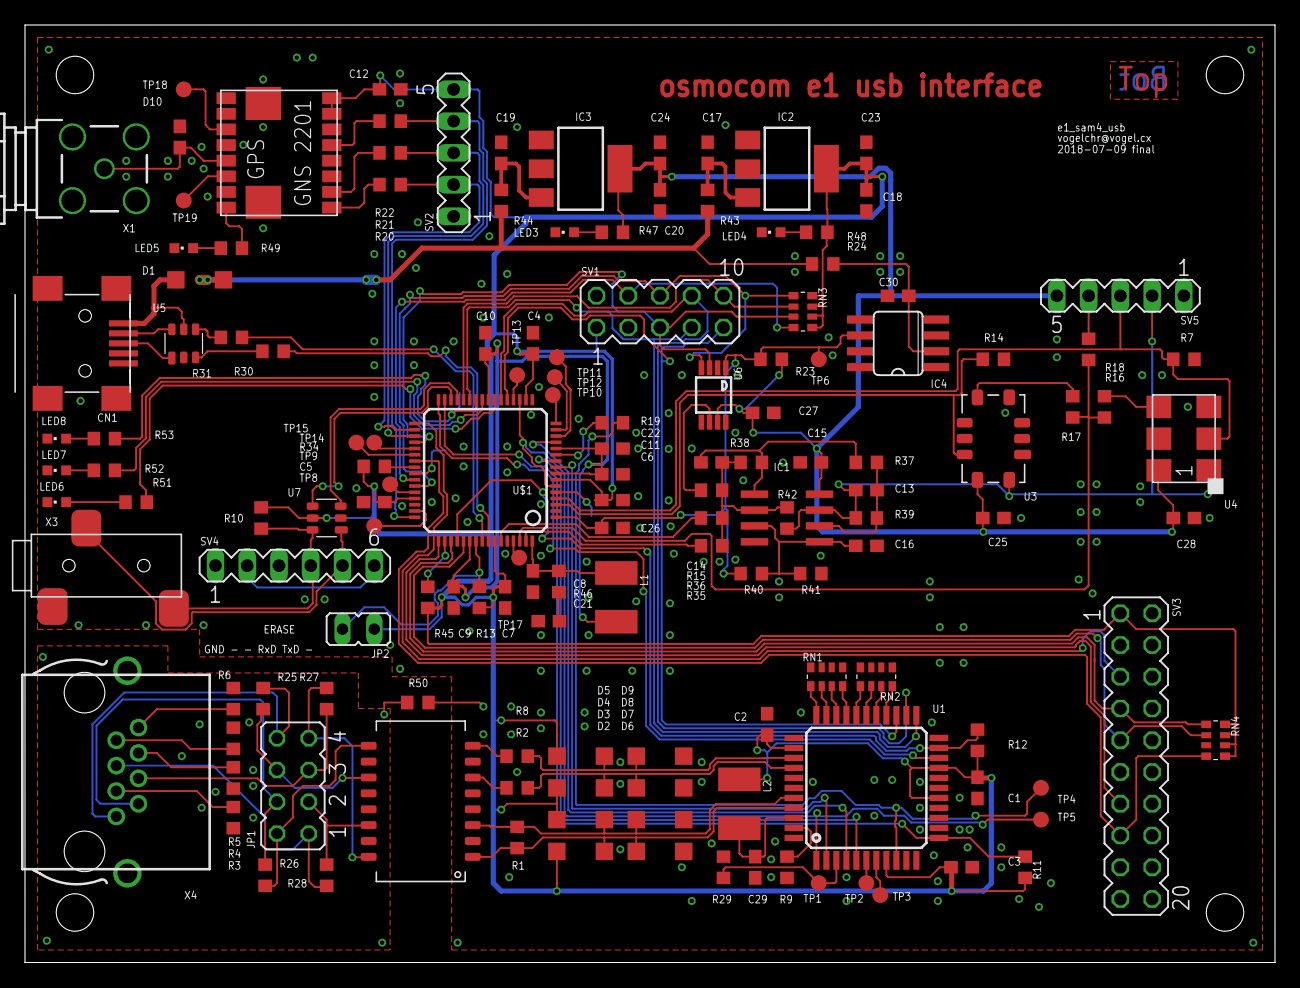
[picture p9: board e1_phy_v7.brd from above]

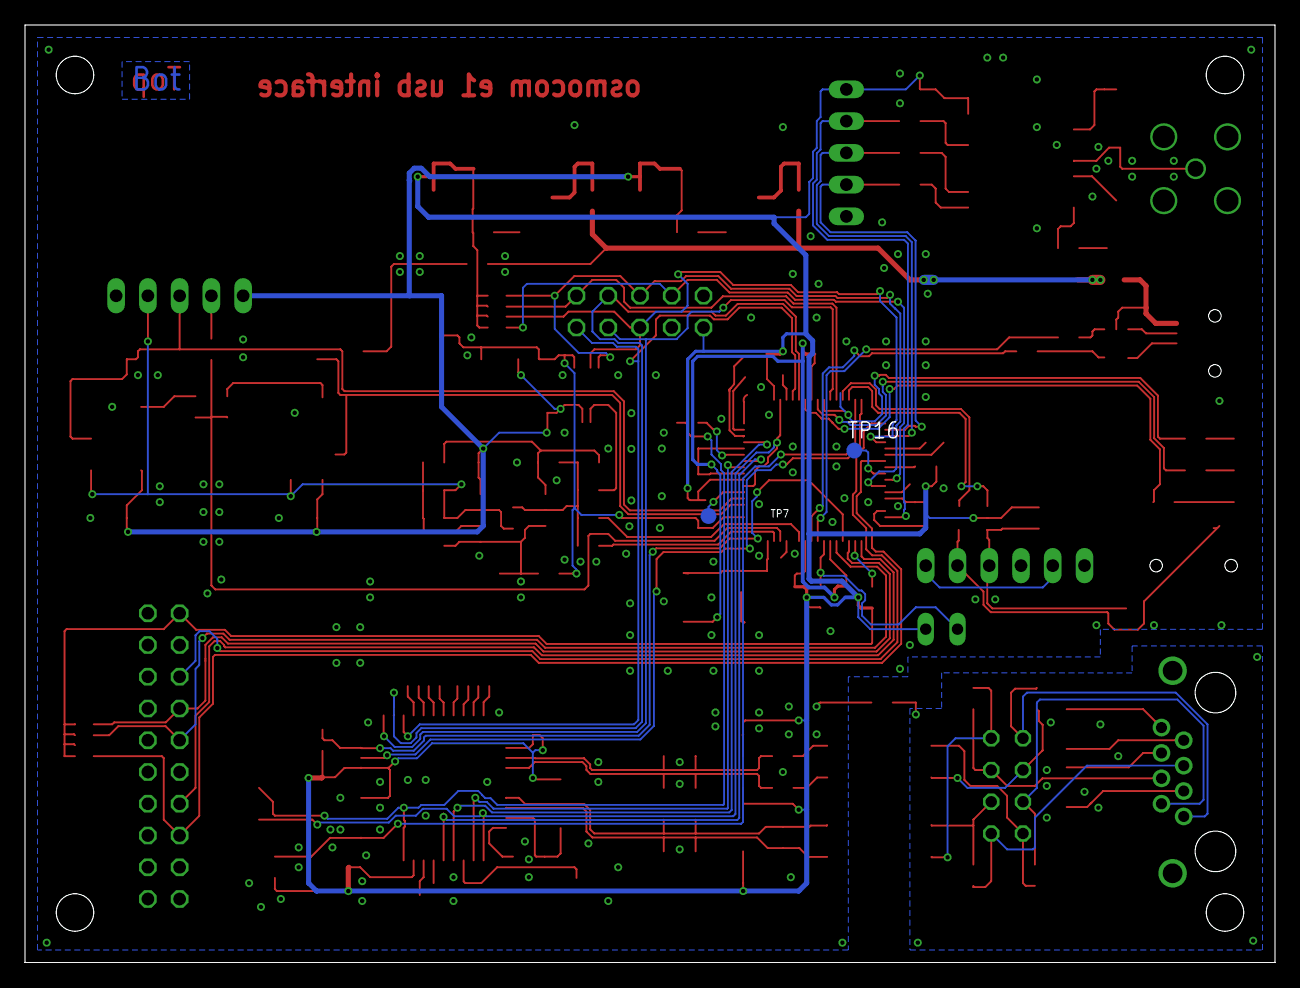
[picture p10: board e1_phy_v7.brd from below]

Board: 2 copper layers, 100.0 x 75.0 mm, 146 parts (2 on the bottom side), 123 nets.

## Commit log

2018-05-16 First commit.
    [e1_phy.brd, e1_phy.sch]
2018-06-24 First sane version, for review.
    I've smashed all the random edits and redesigns into this single commit,
    the history was not useful to keep.
    [e1_phy.brd, e1_phy.sch]
2018-06-24 Add CAM output and .pdf version of schematic & board.
2018-06-25 Pullup on i2c, ERASE jumper.
    [e1_phy_v7.brd, e1_phy_v7.sch]
2018-06-25 Changed LIU to IDT82V2081.
    [e1_phy.brd, e1_phy.sch, e1_phy_v7.brd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]
2018-06-25 Add worksheet with pin allocation for SAM4S.
2018-06-27 Add laforge.lbr.
    https://osmocom.org/attachments/3247/laforge.lbr
2018-06-27 Implement review: ESD protection on USB.
    [e1_phy.brd, e1_phy.sch]
2018-06-27 Implement review comment: R1 120 Ohms, R2, R2 9 Ohs
    Termination on Rx input and output impedance on Tx.
    [e1_phy.brd, e1_phy.sch]
2018-06-27 Implement review comment: LIU move signal from LOS to #INT
    - LIU move signal from LOS to #INT
    -> Interrupt can be generated on LOS anyway.
    [e1_phy.brd, e1_phy.sch]
2018-06-27 Implementation of review comment:
    Removed octal resistor array, introduced quad resistor array,
    will be used for various pullups.
    [e1_phy.brd, e1_phy.sch]
2018-06-27 Implement review comments: Switch DAC to Maxim part.
    [e1_phy.brd, e1_phy.sch]
2018-06-27 More review comments implemented.
    Done:
    - ESD protection on UART
    - changed JTAG to 2x10 standard ARM (but only minimal usage of pins on
    SAM4S)
    - FTDI pinout on serial port header
    - LEDS moved near frontpanel, maybe later exchange by side-emitting
    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
    [e1_phy.brd, e1_phy.sch]
2018-07-03 Implementing further review comments:
    * SPI/I2C header UEXT compatible 2x5
    * Pullups on #RESET & JTAG TCK, TMS = SWDIO, SWCK
    * Pullup on UART RX
    * Pullup on Liu #RST
    [e1_phy.brd, e1_phy.sch]
2018-07-03 Moved LIU VDD_analog from +UB to Vcc+Inductor
    (this is suggested in the datasheet, and I don't want to
    pollute the +UB (clean supply for oscillators))
    [e1_phy.brd, e1_phy.sch]
2018-07-03 Review comments: Add ESD protection on GPS antenna.
    0603ESDA-TR from laforge library.
    [e1_phy.brd, e1_phy.sch]
2018-07-03 Regenerated v7 eagle files, made .pdf for schematic.
    -> next release candidate 20180703
    [e1_phy.brd, e1_phy.sch, e1_phy_v7.brd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]
2018-07-03 Library for MAX5215 / MAX5217 i2c DAC
2018-07-07 33R series resistor in clocks, RX/TX of PPS, SMA through hole
    [e1_phy.brd, e1_phy.sch]
2018-07-07 Add footprint for voltage reference, can be bypassed.
    [e1_phy.brd, e1_phy.sch]
2018-07-07 Testpads for unused LIU signals.
    [e1_phy.brd, e1_phy.sch, e1_phy_v7.brd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]
2018-07-07 Cleaned up silkscreen.
    [e1_phy.brd, e1_phy.sch, e1_phy_v7.brd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]
2018-07-09 Some cleanup before declaring final.
    ADVREF of SAM4S fed by VREF net.
    +UB/2 divider fed by VREF net, renamed to VREF_HALF.
    [e1_phy.brd, e1_phy.sch, e1_phy_v7.brd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]
2018-10-13 Notes during board bringup.
